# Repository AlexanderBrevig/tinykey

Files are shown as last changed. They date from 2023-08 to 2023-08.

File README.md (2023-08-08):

# tinykey

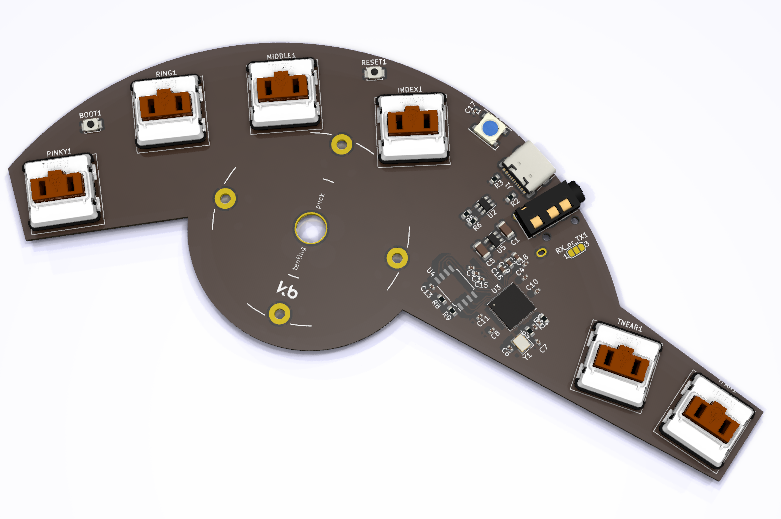
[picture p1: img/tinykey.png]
tinykey design


A project just for fun, to see if I can type on it.

## The rough idea

The layout:

```
↑ ◐ ● ◑ ↹ ⌫      ↩ ␣ ◐ ● ◑ ↓
```

Imagine mapping the home row `ASDFG` to three keys, using chords.
Let's say we only have the `SDF` keys, the mapping will be like this:

```
S = A
SD = S
D = D
DF = F
F = G
```

So, if you wanted to type `SAD` then you would press `SD` `S` `D`. The grouped keys becomes a chord for your ring and middle finger.
Now then, what if you wanted to type `FEAST`?

Notice that `↑` on the pinky? It shifts the home row up.
Before things get crazy, let's rename `SDF` to `◐●◑`.

Now, then `FEAST` becomes:

```
F  E  A S  T
●◑ ↑● ● ◐● ↑◑ 
```

The same applies for the `↓` on the right pinky. This shifts the home row down.

So what about the thumbs then?

The left thumb has two keys, a TAB `↹` and a BACKSPACE `⌫`. 
The right thumb has RETURN `↩` and SPACE `␣`.
However, when held they enter other layers.

In my (still only slideware) config, I've mapped the numbers to the top row on the SPACE layer.
So, for me to type out `1337` it would be:

```
1   3   3   7
↑◐␣ ↑●␣ ↑●␣ ↑␣●◑
```

I will post my complete keymap when it's ready.

## Taking it further

We could also realize five keys by using timing and only two keys.

```
A S   D  F   G
◐ ◐-◑ ◑◐ ◑-◐ ◑
```

S and F has a roll, while D is _at the same time_ (within a confurable Δt ms).

Will try to play with this as well, and thus getting the layout down to 10 keys total.

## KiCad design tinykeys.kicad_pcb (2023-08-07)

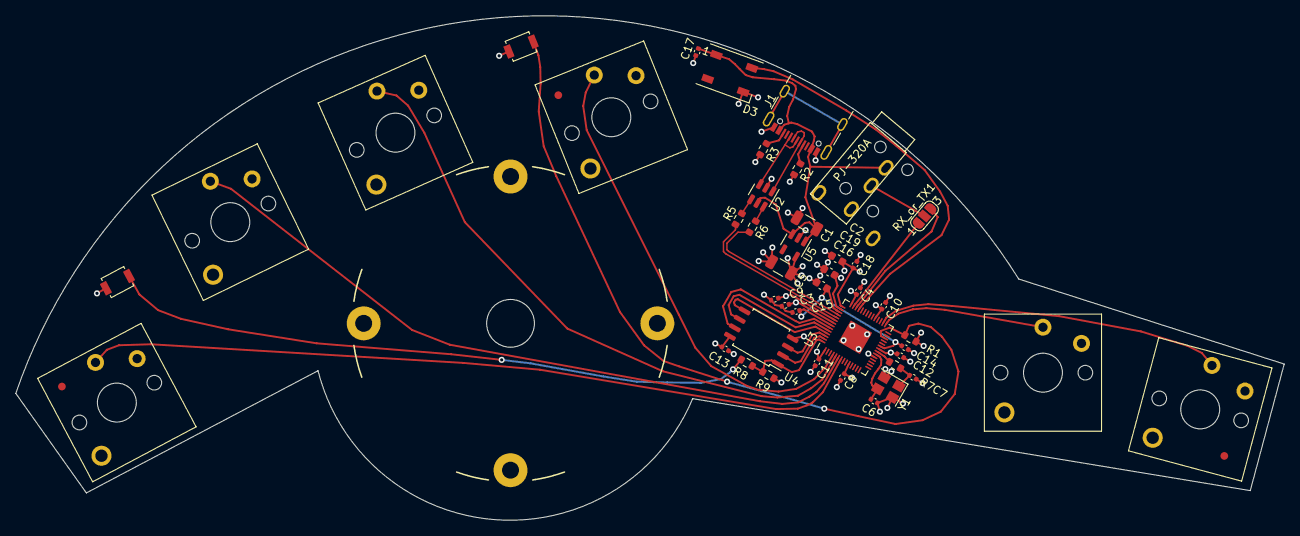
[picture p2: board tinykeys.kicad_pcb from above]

Board: 4 copper layers, 164.6 x 65.4 mm, 48 parts (0 on the bottom side), 33 nets.

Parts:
BOOT1: TACT; SW_SPST_B3U-1000P
C1: DNP; C_1206_3216Metric
C2, C16, C19: 1u; C_0603_1608Metric
C3, C4, C8, C9, C10, C11, C12, C13, C14, C15, C17, C18: 100n; C_0402_1005Metric
C5: 1u; C_1206_3216Metric
C6, C7: 15p; C_0402_1005Metric
D3: WS2812B; LED_WS2812B_PLCC4_5.0x5.0mm_P3.2mm
FID1, FID2, FID3: Fiducial; dualfiducial
H1: MountingHole_Pad; Tenting_Puck
INDEX1: SW; SW_Kailh_Choc_V1V2_1.00u
J1: USB_C_Receptacle_USB2.0; USB_C_Receptacle_GCT_USB4105-xx-A_16P_TopMnt_Horizontal
J2: AudioJack4; TRRS-PJ-320A
MIDDLE1: SW; SW_Kailh_Choc_V1V2_1.00u
PINKY1: SW; SW_Kailh_Choc_V1V2_1.00u
R1, R9: 10k; R_0603_1608Metric
R2, R3: 5K1; R_0603_1608Metric
R5, R6: 27R; R_0603_1608Metric
R7, R8: 1k; R_0603_1608Metric
RESET1: TACT; SW_SPST_B3U-1000P
RING1: SW; SW_Kailh_Choc_V1V2_1.00u
RX_or_TX1: Jumper_3_Open; SolderJumper-3_P1.3mm_Open_RoundedPad1.0x1.5mm_NumberLabels
TFAR1: SW; SW_Kailh_Choc_V1V2_1.00u
TNEAR1: SW; SW_Kailh_Choc_V1V2_1.00u
U2: USBLC6-2SC6; SOT-23-6
U3: RP2040; QFN-56-1EP_7x7mm_P0.4mm_EP3.2x3.2mm
U4: W25Q128JVS; SOIC-8_5.23x5.23mm_P1.27mm
U5: TLV70033DDCR; SOT-23-5
Y1: 12MHz; Crystal_SMD_3225-4Pin_3.2x2.5mm

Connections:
+1V1: C14.1, C15.1, C16.1, U3.23 (DVDD), U3.45 (VREG_VOUT), U3.50 (DVDD)
+3V3: C2.1, C3.1, C4.1, C5.1, C8.1, C9.1, C10.1, C11.1, C12.1, C13.1, C18.1, C19.1, R1.1, R9.1, U3.1 (IOVDD), U3.10 (IOVDD), U3.22 (IOVDD), U3.33 (IOVDD), U3.42 (IOVDD), U3.43 (ADC_AVDD), U3.44 (VREG_IN), U3.48 (USB_VDD), U3.49 (IOVDD), U4.8 (VCC), U5.5 (OUT)
BOOT: BOOT1.2, R8.1
GND: BOOT1.1, C1.2, C2.2, C3.2, C4.2, C5.2, C6.1, C7.1, C8.2, C9.2, C10.2, C11.2, C12.2, C13.2, C14.2, C15.2, C16.2, C17.2, C18.2, C19.2, D3.3 (VSS), H1.1, INDEX1.2, J1.A1 (GND), J1.A12 (GND), J1.B1 (GND), J1.B12 (GND), J2.S, J2.T, MIDDLE1.2, PINKY1.2, R2.2, R3.2, RESET1.1, RING1.2, TFAR1.2, TNEAR1.2, U2.2 (GND), U3.19 (TESTEN), U3.57 (GND), U4.4 (GND), U5.2 (GND), Y1.2, Y1.4
INDEX: INDEX1.1, U3.4 (GPIO2)
MIDDLE: MIDDLE1.1, U3.5 (GPIO3)
unnamed: C7.2, R7.1, Y1.1
unnamed: J1.A5 (CC1), R2.1
unnamed: J1.B5 (CC2), R3.1
unnamed: J2.R1, RX_or_TX1.2 (C)
unnamed: C6.2, U3.20 (XIN), Y1.3
unnamed: R7.2, U3.21 (XOUT)
PINKY: PINKY1.1, U3.7 (GPIO5)
QSPI_SCLK: U3.52 (QSPI_SCLK), U4.6 (CLK)
QSPI_SD0: U3.53 (QSPI_SD0), U4.5 (DI(IO0))
QSPI_SD1: U3.55 (QSPI_SD1), U4.2 (DO(IO1))
QSPI_SD2: U3.54 (QSPI_SD2), U4.3 (IO2)
QSPI_SD3: U3.51 (QSPI_SD3), U4.7 (IO3)
QSPI_~SS: R8.2, R9.2, U3.56 (QSPI_SS), U4.1 (~CS)
RING: RING1.1, U3.6 (GPIO4)
RUN: R1.2, RESET1.2, U3.26 (RUN)
STATUS_LED: D3.4 (DIN), U3.39 (GPIO27_ADC1)
TFAR: TFAR1.1, U3.30 (GPIO19)
TNEAR: TNEAR1.1, U3.29 (GPIO18)
UART0_RX: RX_or_TX1.1 (A), U3.41 (GPIO29_ADC3)
UART0_TX: RX_or_TX1.3 (B), U3.40 (GPIO28_ADC2)
USB_D+: R5.1, U2.4 (I/O2)
USB_D-: R6.1, U2.6 (I/O1)
USB_FIL_D+: R5.2, U3.47 (USB_DP)
USB_FIL_D-: R6.2, U3.46 (USB_DM)
USB_RAW_D+: J1.A6 (D+), J1.B6 (D+), U2.3 (I/O2)
USB_RAW_D-: J1.A7 (D-), J1.B7 (D-), U2.1 (I/O1)
VBUS: C1.1, C17.1, D3.1 (VDD), J1.A4 (VBUS), J1.A9 (VBUS), J1.B4 (VBUS), J1.B9 (VBUS), J2.R2, U2.5 (VBUS), U5.1 (IN), U5.3 (EN)
